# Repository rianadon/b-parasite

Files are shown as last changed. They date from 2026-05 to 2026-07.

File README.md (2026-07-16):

# b-parasite
<p align="center">
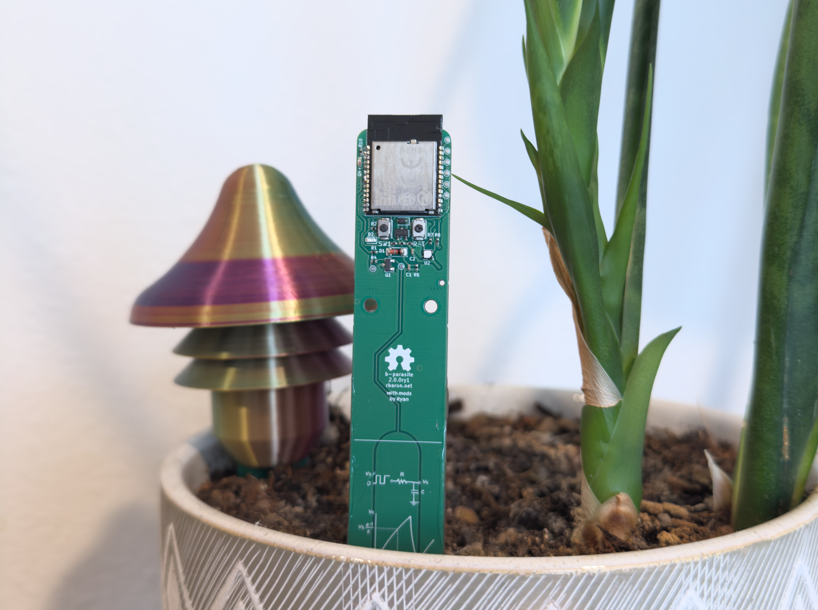
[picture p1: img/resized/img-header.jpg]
PCB in the soil
  <br>
  <i>This image is just for showing off the full PCB.<br>The sensor must be pushed down to the horizontal white line to work properly.</i>
</p>

<a href='https://cosmos-store.ryanis.cool/products/b-parasite-soil-moisture-sensor' target="_blank">Buy at Cosmos Store</a>

This is my fork of [b-parasite](https://github.com/rbaron/b-parasite), an open source soil moisture and ambient temperature/humidity/light sensor. Notable changes are:
- I changed the bluetooth module to MinewSemi nrf52840-MS88SF21 because I have extra from other projects.
- I've added a USB-C connector, and the bluetooth module is programmed with the [Adafruit nRF52 bootloader](https://github.com/rianadon/Adafruit_nRF52_Bootloader). The module can now be powered by either the coin cell and/or USB. If both are plugged in, priority is given to USB. Do be careful to ground yourself before plugging in USB. There was not room for ESD diodes on the PCB.
- Instead of feeding the battery directly to the chip voltage, I utilize the internal LDO to step down the voltage. This has several benefits. Battery life is extended due to running the chip and wireless transmitter at lower voltage, wireless transmission is consistent regardless of battery voltage, and there is no need to calibrate across different voltages. Only 1 measurement each of wet/dry moisture and sun luminosity are required to calibrate the sensor.
- Utilizing a USB COM port, calibration can now easily be performed without any specialized hardware.
- I've changed a few components to what's in stock on LCSC. The most noticeable of these is I replaced the Sensirion SHTC3, which was not in stock at the time of ordering, with a cheap clone. It's accurate within a few degrees F.

<p align="center">
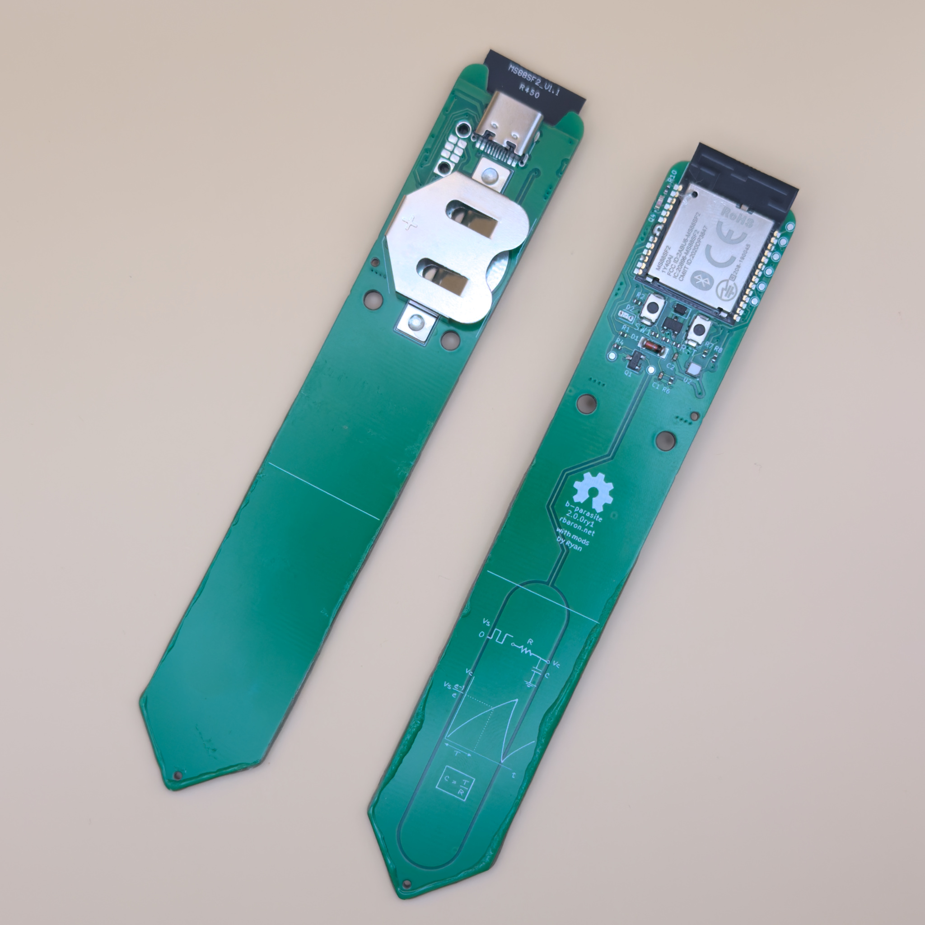
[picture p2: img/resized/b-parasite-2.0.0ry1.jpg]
PCB front and back photo
  
</p>

Instead of version tags I publish the software binaries on every commit. Check the [releases](https://github.com/rianadon/b-parasite/releases) to grab your preferred UF2. There are binaries for both BLE and Zigbee. I've tested both; while BLE is supposedly the more stable one I've been using Zigbee without issues.

To upload code, plug the b-parasite into your computer with a usb-c cable and press the reset button (RST) two times in quick succession. It's circled in red below. The LED (D2) will start pulsing in and out, and you'll see a removable drive named `BPARASITE` appear. Drag your `.uf2` file over to this drive (or copy and paste it in). Once it's copied, the microcontroller will automatically reboot with the new firmware. For building the firmware yourself or performing your own calibration, see [code/README.md](code/README.md).

<p align="center">
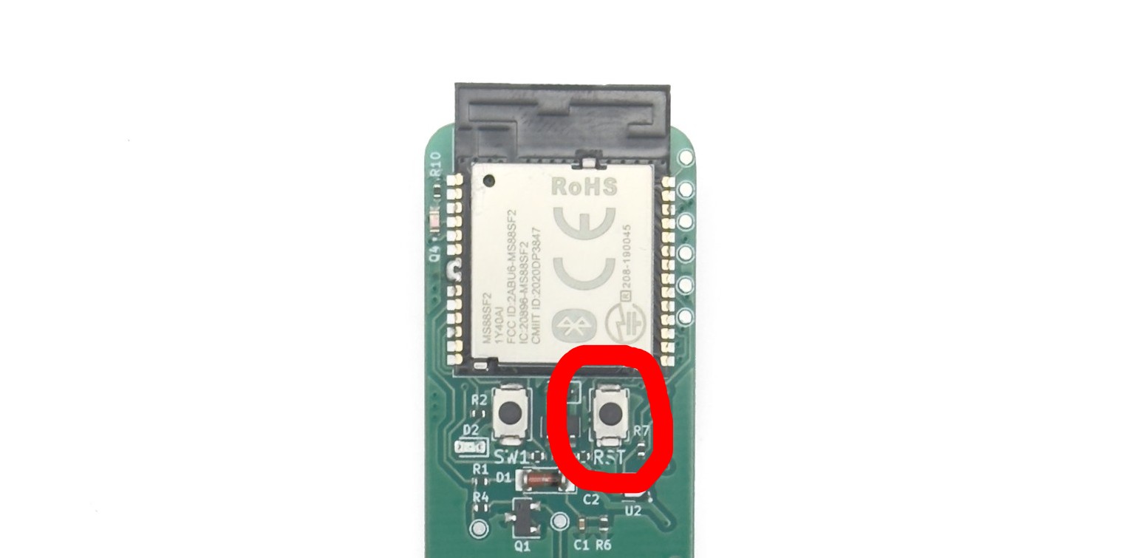
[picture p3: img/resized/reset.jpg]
location of reset button on the PCB
    
</p>

**Errata:** On the PCB I accidentally routed the sensor to P0.26, which does not support analog input. Therefore I've solder bridged P0.26 to P0.04 and used P0.04 as the sensor pin in the code. If you are manufacturing the PCBs in my fork yourself, I suggest you edit the PCB to connect SENS_OUT to P0.04 so that the solder bridge is not required.

Speaking of building these yourself, the most economical option is to order the PCBs with only the top soldered then solder on the USB connector and coin cell holder yourself with a stencil.

The original README is below:

---------------

b-parasite is an open source soil moisture and ambient temperature/humidity/light sensor.

# Features
* Capacitive Soil moisture sensor - see [this blog post](https://rbaron.net/blog/2021/04/05/How-capacitive-soil-moisture-sensors-work.html), [this Twitter thread](https://twitter.com/rbaron_/status/1367182806368071685), and [this post](https://wemakethings.net/2012/09/26/capacitance_measurement/) for nice resources on how they work
* Air temperature and humidity sensor using a [Sensirion's SHTC3](https://www.sensirion.com/en/environmental-sensors/humidity-sensors/digital-humidity-sensor-shtc3-our-new-standard-for-consumer-electronics/)
* Light sensor using an [ALS-PT19](https://en.everlight.com/wp-content/plugins/ItemRelationship/product_files/pdf/ALS-PT19-315C-L177-TR8_V8.pdf) phototransistor
* Powered by a common CR2032 coin cell, potentially for over two years
* Support for [nRF52840](https://www.nordicsemi.com/products/nrf52840) and [nRF52833](https://www.nordicsemi.com/products/nrf52833) modules
* Open hardware and open source design

# Software
This repository also hosts a few different firmware samples for b-parasite.

|Sample|Description|Extra Documentation|
|---|---|---|
|[samples/ble](./code/samples/ble)|This is the most battle-tested and useful firmware. It periodically reads all sensors and broadcast them via Bluetooth Low Energy (BLE). It works with [Home Assistant](https://www.home-assistant.io/) + [BTHome](https://bthome.io/) out of the box. |[Docs](./code/samples/ble/README.md)|
|[samples/zigbee](./code/samples/zigbee)| An experimental/educational/exploratory basic Zigbee sample built on [nRF Connect + ZBOSS](https://developer.nordicsemi.com/nRF_Connect_SDK/doc/latest/nrf/ug_zigbee.html). It integrates with [Home Assistant](https://www.home-assistant.io/) via [ZHA](https://www.home-assistant.io/integrations/zha) or [Zigbee2MQTT](https://www.zigbee2mqtt.io/). |[Docs](./code/samples/zigbee/README.md)|
|[samples/blinky](./code/samples/blinky)| The classic "Hello, world" |-|
|[samples/soil-read-loop](./code/samples/soil-read-loop)| Reads the soil moisture sensor on a loop. Useful for experimenting and calibrating the sensor. |-|
|[samples/input](./code/samples/input)| Handles button presses. Useful for power profiling GPIO interrupts and testing debouncing for push switches on [boards that have them](https://github.com/rbaron/b-parasite/wiki/Hardware-Versions). |-|

# Documentation
Information about how to order, assemble, build the samples, protect the sensor and flash the firmware is on [the Wiki](https://github.com/rbaron/b-parasite/wiki).

# Repository Organization
* [code/](./code/) - A [`west workspace`](https://docs.zephyrproject.org/latest/develop/west/workspaces.html) containing the common `prstlib` module library and samples, built with Nordic's [nRF Connect SDK](https://www.nordicsemi.com/Products/Development-software/nrf-connect-sdk).
* [kicad/](./kicad/) - KiCad schematic, layout and fabrication files for the printed circuit board (PCB)
* [data/](data/) - data for testing and sensor calibration
* [bridge/](bridge/) - an [ESPHome](https://github.com/esphome/esphome)-based BLE-MQTT bridge
* [case/](case/) - a 3D printable case

<p align="center">
  b-parasite stuck into a small plant vase
</p>

# Case
<p align="center">
  Render of the original 3D printable case
</p>

We have three different 3D-printable cases:
1. Original snap-on case - [case/Top.stl](./case/Top.stl), [case/Bottom.stl](./case/Bottom.stl)
2. High airflow - [case/b_parasite_case_high_airflow.stl](./case/b_parasite_case_high_airflow.stl)
3. Mushroom-style - available on [Printables](https://www.printables.com/model/456571-mushroomcap-for-b-parasite-soil-moisture-sensor)
4. b-parasite Hat - available on [Printables](https://www.printables.com/model/901220-waterproof-case-for-b-parasite-soil-moisture-air-s)

# Accessories

Designs and hardware to help you, when building your own:
1. Desk holder for b-parasites [Printables](https://www.printables.com/de/model/566974-b-parasite-holder)

# License
The hardware and associated design files are released under the [Creative Commons CC BY-SA 4.0 license](https://creativecommons.org/licenses/by-sa/4.0/).
The code is released under the [MIT license](https://opensource.org/licenses/MIT).

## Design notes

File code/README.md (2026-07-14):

# b-parasite Firmware

This documentation is common to all firmwares inside the `code/` directory and covers general things like building, configuring common options, and flashing. Each firmware also has its own documentation which you should also read:

- [`samples/ble/README.md`](./samples/ble/README.md) — BLE advertising (BTHome / legacy b-parasite encoding)
- [`samples/zigbee/README.md`](./samples/zigbee/README.md) — Zigbee end device (ZHA / Zigbee2MQTT)

The instructions here are written to only apply to my `2.0.0ry1` revision (both hardware and software). For the older revision, you should refer to the original b-parasite documentation.

## Building

Use either [`scripts/build.sh`](./scripts/build.sh) or [`scripts/build-with-docker.sh`](./scripts/build-with-docker.sh) to build the firmware. I recommend using Docker (or Podman) if you have it installed.

```bash
# For BLE. Generates samples/ble/build_nrf52840_2.0.0ry1_dev/ble/zephyr/zephyr.uf2
scripts/build.sh ble nrf52840 2.0.0ry1 --uf2 -DCONFIG_BPARASITE_REGOUT0_2V1=y

# For Zigbee. Generates code/samples/zigbee/build_nrf52840_2.0.0ry1/zigbee/zephyr/zephyr.uf2
scripts/build.sh zigbee nrf52840 2.0.0ry1 --uf2  -DCONFIG_BPARASITE_REGOUT0_2V1=y
```

### Development Builds

Passing `--dev` applies the following modifications to the firmware:

- **Logs Sensor Readings Over USB Serial Port.**. Configures Zephyr to log to a USB CDC ACM virtual UART
- **Increases Log Verbosity**. `CONFIG_LOG_DEFAULT_LEVEL=4` + `CONFIG_PRSTLIB_LOG_LEVEL_DBG=y`
- **Samples much faster**. A shortened wake cadence (each sample picks its own — see `CONFIG_PRSTLIB_DEV_FAST_LOOP`)

The serial port will appear as COM* on Windows, `/dev/ttyACM*` on Linux, and `/dev/cu.usbmodem*` on MacOS. I've switched from screen to picocom to now [tio](https://github.com/tio/tio), which I wholeheartedly recommend, for connecting to serial device over the terminal.

```bash
# For a BLE development build. Generates
# samples/ble/build_nrf52840_2.0.0ry1_dev/zephyr/zephyr.uf2
scripts/build.sh ble nrf52840 2.0.0ry1 --uf2 --dev  -DCONFIG_BPARASITE_REGOUT0_2V1=y
```

Enabling USB hardware and sampling at the fast rate will quickly drain your battery. The dev builds are meant to be used when you have the b-parasite connected to USB.

## Selecting The Regulated Voltage

One of the changes I've made on the PCB is to wire `VDD` independently of `VDDH`, so you can utilize the internal LDO on the nRF52840 to step down the voltage. The lower the voltage, the longer your battery life but the weaker your wireless antenna. To change the voltage, add `-DCONFIG_BPARASITE_REGOUT0_*V*=y`) to the end of your `build.sh` command. The default is `REGOUT0_2V1`.

The choice also drives `CONFIG_BT_CTLR_TX_PWR_*`, which configures how powerful your radio will be. If you want finer control, you can override it with `-DCONFIG_PRSTLIB_RADIO_TX_PWR_DBM=0`/`4`/`8`.

| Kconfig | Chip VDD | BLE TX cap | Best for | Readings accurate down to | CR2032 life (ai estimate) |
|---|---|---|---|---|---|
| `REGOUT0_1V8` | 1.8 V | 0 dBm | Best battery life, but voltage is too low for LED to turn on | 1.3% battery | ~3.5 yr |
| `REGOUT0_2V1` | 2.1 V | 0 dBm | Recommended default for indoors. In cold temperatures, the voltage may be too low for the LED. | 5.4% battery | ~2.5–3.7 yr |
| `REGOUT0_2V4` | 2.4 V | +4 dBm | Recommended for outdoors due to more wireless range and greater LED voltage. | 16.4% battery | ~2.0–3.0 yr |

There's also `REGOUT0_2V7` (+4dBm), `REGOUT0_3V0` (+8dBm) and `REGOUT0_3V3` (+8dBm).  However, for all of these the sensor readings will scale linearly with voltage as the battery drops, instead of remaining stable. This is because the onboard LDO requires VDDH > VDD+0.3V to be stable, and CR2032 starts at 3.0V.

The voltage setting is stored in UICR flash. When the chip is booted with the firmware for the first time, it will write UICR and reboot if the voltage setting changed.

## Calibrating the Sensors

Because the LDO ensures a stable supply voltage, only one measurement is needed for calibrating the soil and light sensors.

Procedure:

1. Load a firmware with development mode (`--dev`) turned on (see *Development Builds* above) **with the same voltage configured that you will use in your firmware** . Open the serial port.
2. With the sensor sitting in **outside soil** and touching nothing, wait for log lines like:
    ```
    Read soil moisture 2: -3.24 | Raw 508 | V_drive: 2.10 | Dry: 510 | Wet: 179
    ```
   Record the **Raw** value (here, `508`) — this is your `PRSTLIB_SOIL_DRY_RAW`. Ignore "Dry"/"Wet"—they are the calibration the firmware is currently using.
3. With the sensor sitting outside or near sunlight, record the phototransistor value as well as the lux from your smartphone (there are quite a few lux meters). Look for the line that reads
    ```
    Photo: 687 lx (116 mV)
    ```
    Disregard the lux reading here, since that uses the firmware's preexisting calibration. Instead calculate `PRSTLIB_PHOTO_CURRENT_SUN_UA` = 21277 × reported current (mV) ÷ phone's illuminance reading (lux).
3. Submerge the sensor pads in tap water up to the printed line on the circuit board. Use the same Raw reading in step 2, which is now your `PRSTLIB_SOIL_WET_RAW`.
4. Build the UF2

```
./scripts/build.sh ble nrf52840 2.0.0ry1 --uf2 \
  -DCONFIG_BPARASITE_REGOUT0_2V1=y \
  -DCONFIG_PRSTLIB_SOIL_DRY_RAW=510 \
  -DCONFIG_PRSTLIB_SOIL_WET_RAW=170 \
  -DCONFIG_PRSTLIB_PHOTO_CURRENT_SUN_UA=3546
```

For the Zigbee firmware, replace `ble` with `zigbee`.

## Bootloader

I flash the Adafruit UF2 bootloader to the board. The b-parasite specific configuration is located in [my Adafruit_nRF52_Bootloader fork](https://github.com/rianadon/Adafruit_nRF52_Bootloader).

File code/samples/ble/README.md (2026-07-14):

# Bluetooth Low Energy (BLE)
In this sample, b-parasite sensors are periodically read and broadcast using Bluetooth Low Energy (BLE) dvertising packets.

## Configuration
Available configurations and their default values are in [`Kconfig`](./Kconfig). They are set in [`prj.conf`](./prj.conf). Here are some notable examples.

### Sleep Interval
To save energy, the board spends most of the time in a "deep sleep" state, in which most peripherals and radio are completely turned off. The period of sleep is controlled by the `PRST_SLEEP_DURATION_SEC` config.

### Advertising Duration
When it wakes up, the sample reads all sensors and keep broadcasting advertising packets for `PRST_BLE_ADV_DURATION_MSEC` before going back to sleep.

### Advertising Packet Encoding
There are different ways to encode the sensor data in a BLE advertising packet.

#### BTHome Encoding
[BTHome](https://bthome.io) is a new (as of Dec/2022) open standard for encoding sensor data in BLE applications. [Home Assistant](https://www.home-assistant.io/integrations/bthome/) supports it out of the box. This makes the deployment extra convenient, since no additional configuration is needed - Home Assistant will automatically detect b-parasites in range.

What's even more interesting is that by employing [ESPHome](https://esphome.io/) bridges with the [`bluetooth_proxy`](https://esphome.io/components/bluetooth_proxy.html) component, the range of BLE coverage can be transparently increased. Multiple ESPHome bridges will forward received BLE broadcasts to Home Assistant.

This is what a typical deployment with BTHome looks like:
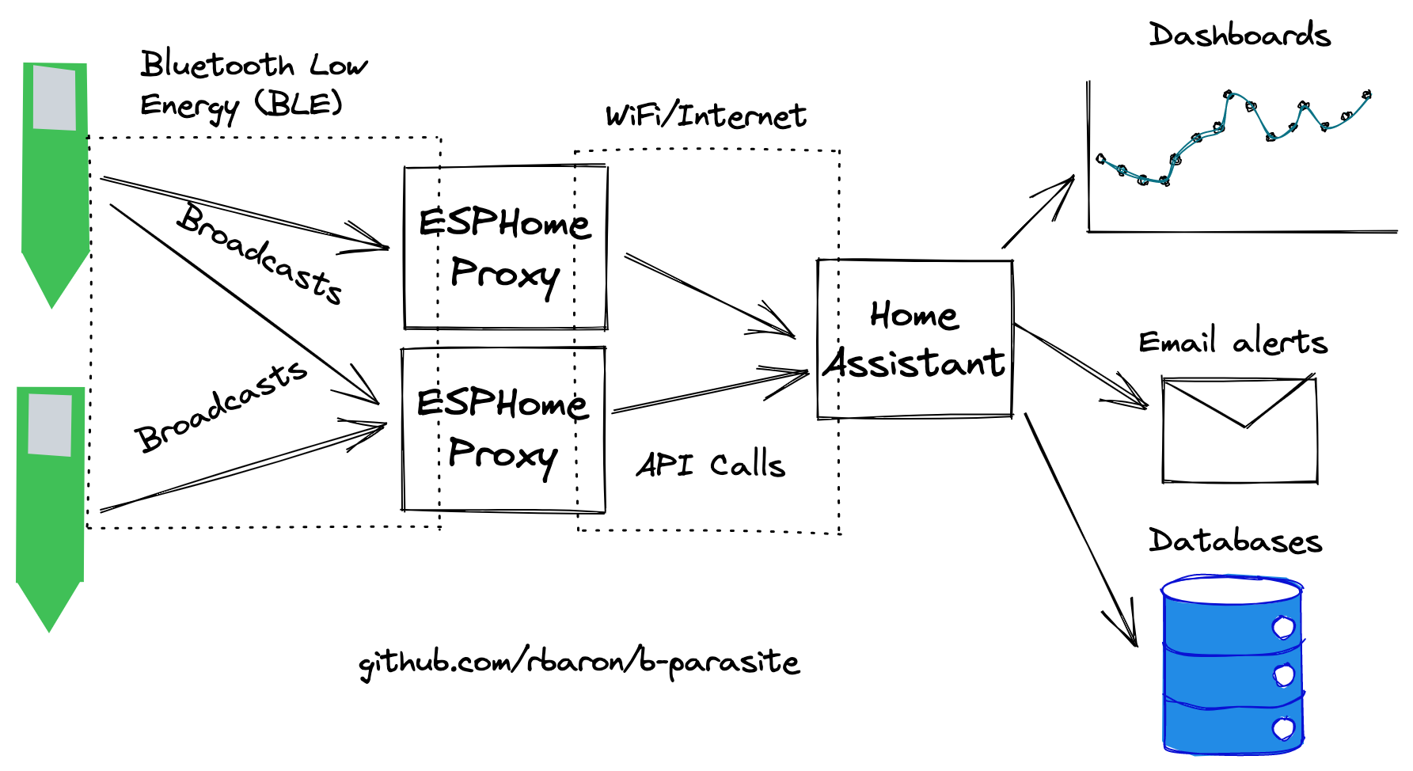
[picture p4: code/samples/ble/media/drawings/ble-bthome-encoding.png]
Topology with BTHome + Home Assistant


There are two versions of BTHome encodings supported by this sample:
* `PRST_BLE_ENCODING_BTHOME_V2=y` (**default**) uses the [BTHome V2](https://bthome.io/format/), supported by Home Assistant since version `2022.12`
* `PRST_BLE_ENCODING_BTHOME_V1=y` uses the [legacy BTHome V1](https://bthome.io/v1/), which was briefly in use
#### b-parasite Encoding
`PRST_BLE_ENCODING_BPARASITE_V2=y` selects the legacy encoding, used historically in this project. This is the encoding that the [`b_parasite`](https://esphome.io/components/sensor/b_parasite.html) ESPHome component understands.

With this encoding and a ESPHome + `b_parasite` component, this is an usual deployment topology:

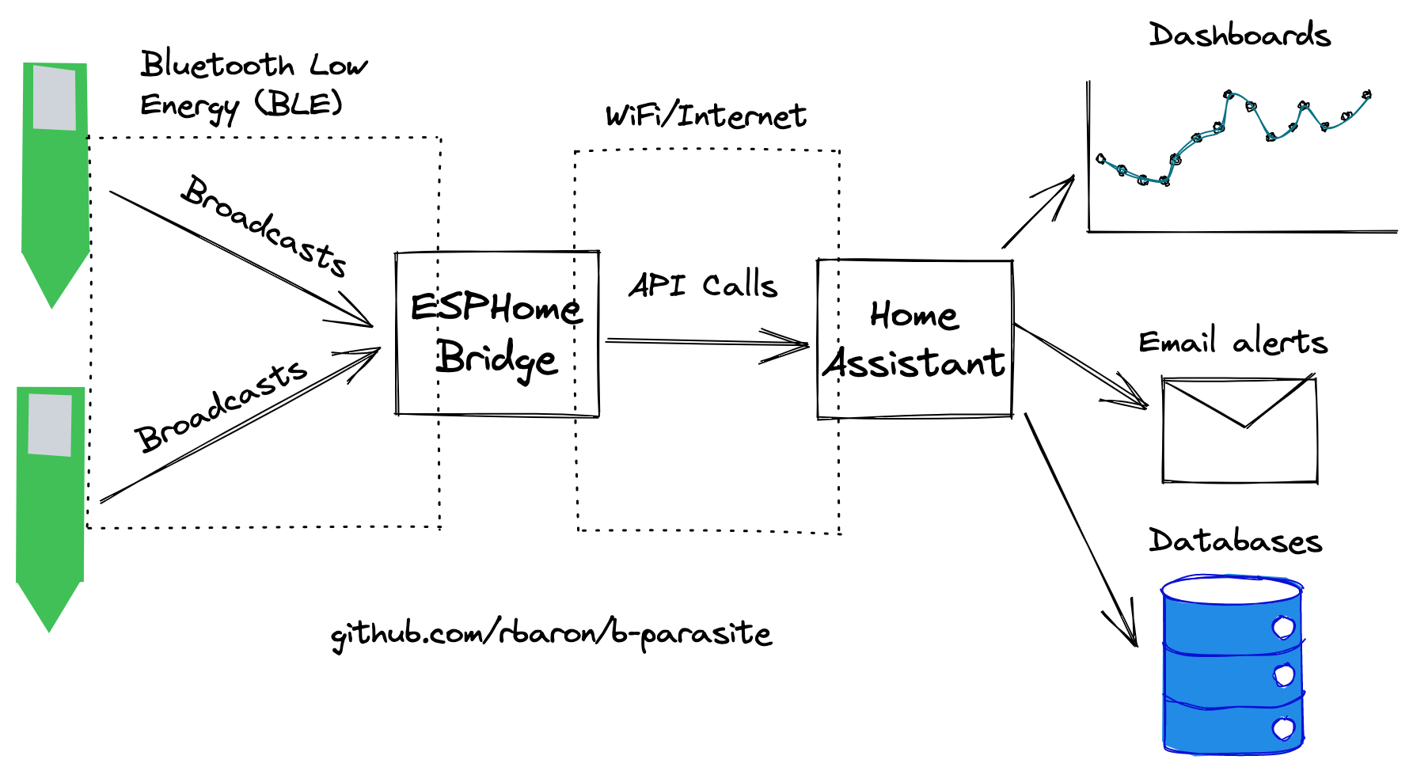
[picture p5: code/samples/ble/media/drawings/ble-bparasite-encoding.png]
Topology with Legacy encoding + Home Assistant


The disadvantages of this encoding are:
- Each b-parasite has to be configured in the ESPHome component
- Range is limited, unless multiple ESPHome bridges are deployed with the same static configuration

## Building

See [`code/README.md`](../../README.md) for the build script, the container wrapper, the `REGOUT0` voltage table, and the soil-moisture calibration procedure — all shared with the zigbee sample. What follows is ble-specific.

### Production build (deploy to battery)

Default `prj.conf` settings: 10-min wake cadence, 1-s advertise window, no USB stack, no logging. Pair with the `2.0.0ry1` board revision (CR2032 wired to VDDH) and pick a `REGOUT0` voltage that matches your hardware (see [`prstlib/boards/bparasite/Kconfig.regout0`](../../prstlib/boards/bparasite/Kconfig.regout0)).

```
./scripts/build-with-docker.sh ble nrf52840 2.0.0ry1 --uf2 \
  -DCONFIG_BPARASITE_REGOUT0_2V1=y
```

Output: `samples/ble/build_nrf52840_2.0.0ry1/ble/zephyr/zephyr.uf2` (~400 KB).

BLE picks its `CONFIG_BT_CTLR_TX_PWR_*` choice from `PRSTLIB_RADIO_TX_PWR_DBM`, which the `REGOUT0` choice sets (0 dBm at 1.8–2.1 V, 4 at 2.4–2.7 V, 8 at 3.0–3.3 V).

### Development build (bring-up, sensor calibration, debugging)

Same command + `--dev` (see [`code/README.md`](../../README.md#development-builds) for what the snippet turns on). For ble it also sets `CONFIG_PRST_SLEEP_DURATION_MSEC=5000`, advertising every ~6 s instead of every 10 min.

```
./scripts/build-with-docker.sh ble nrf52840 2.0.0ry1 --uf2 --dev \
  -DCONFIG_BPARASITE_REGOUT0_2V1=y
```

Output: `samples/ble/build_nrf52840_2.0.0ry1_dev/ble/zephyr/zephyr.uf2` (~445 KB).

## Battery Life
**tl;dr**: Theoretically well over two years with default settings.

While in deep sleep, the board consumes around `3.0 uA`:

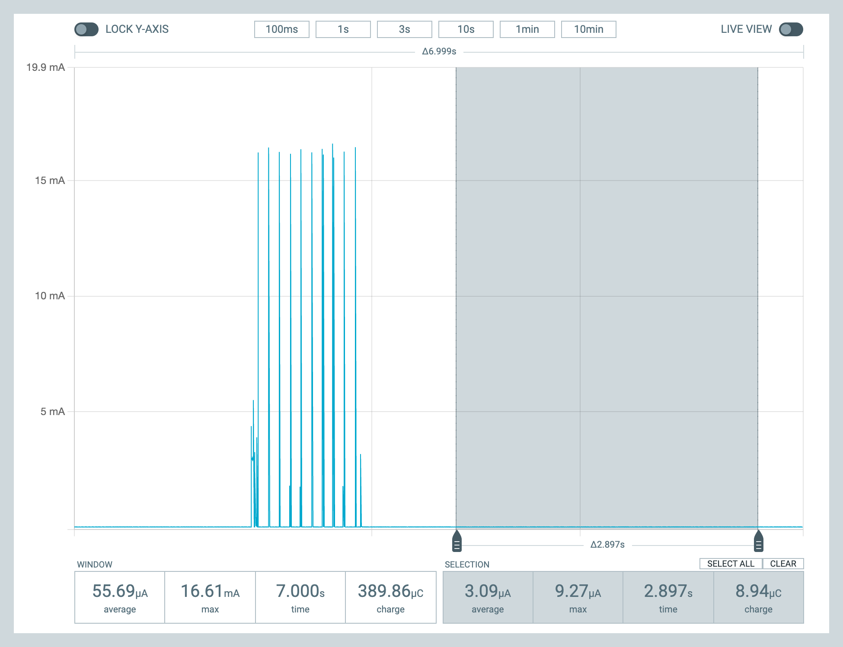
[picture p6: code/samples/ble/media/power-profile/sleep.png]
Sleep current consumption


In the active broadcasting state, the average power consumption is highly dependant on the advertising interval.

With the default settings (in the `[30, 40] ms` range), we see an average of around `810 uA`:

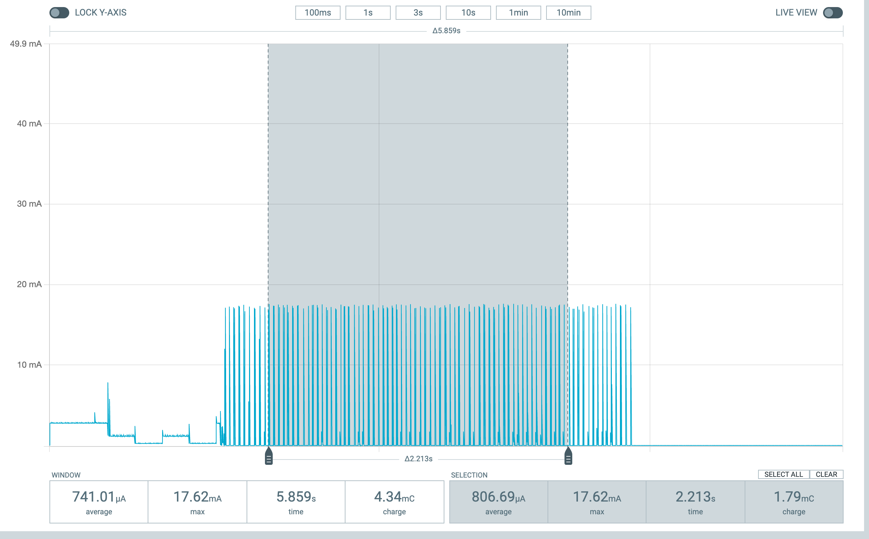
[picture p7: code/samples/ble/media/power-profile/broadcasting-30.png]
Broadcasting with 30 ms current consumption


If for example we lower the connection interval to the SDK defaults (`[100, 150] ms`, roughly trading off range for power), the average current consumption is around `345 uA`:

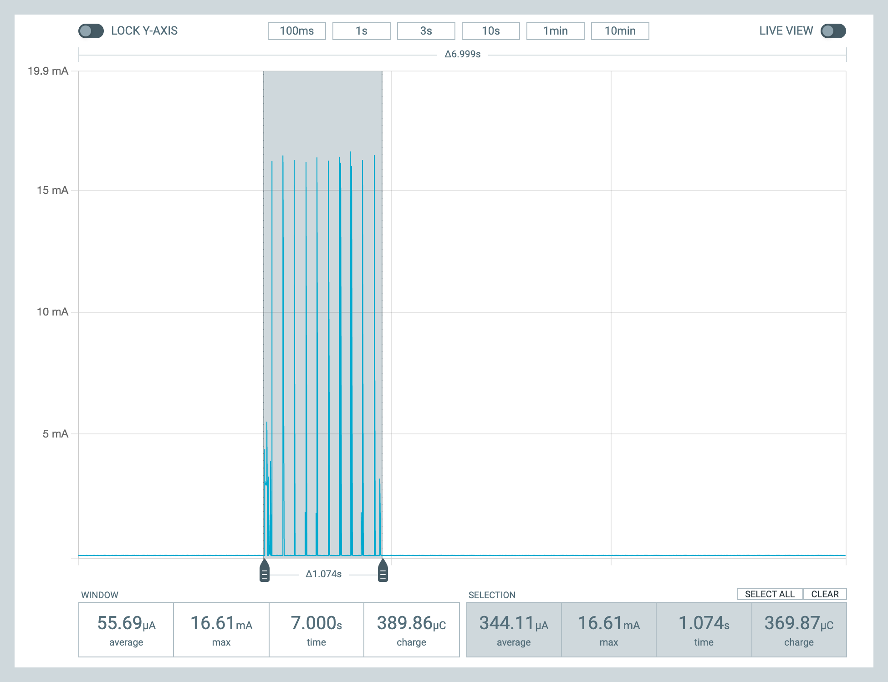
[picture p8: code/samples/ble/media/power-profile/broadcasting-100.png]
Broadcasting with 100ms current consumption


With a `200 mAh` CR2032 battery, we can use [this spreadsheet](https://docs.google.com/spreadsheets/d/157JQiX20bGkTrlbvWbWRrs_WViL3MgVZffSCWRR7uAI/edit#gid=0) to estimate the battery life to over two years. Note that this is a simplified model and results in practice may vary.

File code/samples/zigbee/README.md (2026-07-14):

# Zigbee firmware sample
This sample is adapted from the [zigbee_template](https://developer.nordicsemi.com/nRF_Connect_SDK/doc/latest/nrf/samples/zigbee/template/README.html) from the nRF Connect SDK. It's a basic experimental/educational/exploratory firmware sample for b-parasite.

## Clusters
These [clusters](https://en.wikipedia.org/wiki/Zigbee#Cluster_library) are defined in the sample:

|Cluster ID|Name|
|---|---|
|0x0001|Power Configuration|
|0x0400|Illuminance Measurement|
|0x0402|Temperature Measurement|
|0x0405|Relative Humidity Measurement|
|0x0408|Soil Moisture Measurement|

## Pairing Mode
The sample will first boot and start looking for a Zigbee coordinator - in pairing mode. The onboard LED will be flashing once a second while in this mode. Once a suitable network is found, the LED will briefly flash 3 times and remain off.

### Factory Reset
A factory reset will make b-parasite forget its network pairing information and switch to pairing mode. There are two (mutually exclusive) methods to perform a factory reset, controlled by the `CONFIG_PRST_ZB_FACTORY_RESET_METHOD` config flag.

#### Factory Reset Method 1 (default) - Double reset
Resetting b-parasite twice in the timestamp of 5 seconds will perform a factory reset. With this method, both shorting the `RST` pin to ground and removing-inserting the battery counts as a reset.

For better results, wait > 1 and < 5 seconds second between the resets. The LED will flash a total of 8 times to indicate it worked.

#### Factory Reset Method 2 - Reset Pin
In this method, there's a distinction between two reset modes.

#### Power up mode
The device enters this mode when it is powered. For example, swapping an old battery or connecting to eternal power. This is the "usual" reset mode, and joined networks will be remembered.

#### Reset pin mode
If the device's RESET pin is briefly grounded, the device will effectively be **factory reset**. The device will leave its previous network and start looking for a new one.

While it works, this method can be finicky - an accidental pin reset will perform an unwanted factory reset.

## Configs
Available options in `Kconfig`. Notable options:
* `CONFIG_PRST_ZB_SLEEP_DURATION_SEC`: amount of time (in seconds) the device sleeps between reading all sensors and updating its clusters
* `CONFIG_PRST_ZB_PARENT_POLL_INTERVAL_SEC`: amount of time (in seconds) the device waits between polling its parent for data

## Home Assistant Integration
This firmware sample has only been tested with Home Assistant, using one of the following integrations.

### Zigbee Home Automation (ZHA)
With the [ZHA](https://www.home-assistant.io/integrations/zha) Home Assistant integration, b-parasite should work out of the box.

### Zigbee2MQTT & Home Assistant
With [Zigbee2MQTT](https://zigbee2mqtt.io/), a custom converter is required. The [b-parasite.js](b-parasite.js) file contains such a converter. See [Support new devices](https://www.zigbee2mqtt.io/advanced/support-new-devices/01_support_new_devices.html) for instructions.

## Building

See [`code/README.md`](../../README.md) for the build script, the container wrapper, the `REGOUT0` voltage table, and the soil-moisture calibration procedure — all shared with the ble sample. What follows is zigbee-specific.

### Radio TX power

**Note on Zigbee radio TX power:** ZBOSS in NCS routes TX power through its own path (`zb_trans_set_tx_power()`) rather than `CONFIG_NET_L2_IEEE802154_RADIO_DFLT_TX_POWER`, so the board defconfig's `BT_CTLR_TX_PWR_*` choice doesn't reach it. Instead, `main.c` reads `CONFIG_PRSTLIB_RADIO_TX_PWR_DBM` (derived from `REGOUT0` in [`Kconfig.defconfig`](../../prstlib/boards/bparasite/Kconfig.defconfig)) and calls `zb_trans_set_tx_power()` right after `zigbee_enable()`. To override, set `CONFIG_PRSTLIB_RADIO_TX_PWR_DBM=<dBm>` in your build.

### Partition layout

NCS Zigbee NVRAM (`ncs-zigbee/subsys/osif/zb_nrf_nvram.c`) hard-includes `pm_config.h`, so unlike the other samples we can't disable Partition Manager. Instead, [`pm_static.yml`](./pm_static.yml) pins the partitions to match the Adafruit UF2 bootloader:

| Region | Range | Purpose |
|---|---|---|
| `softdevice_reserved` | 0x000000–0x026000 | MBR + SoftDevice slot (reserved, unused) |
| `app` | 0x026000–0x0EC000 | 792 KiB application image |
| `settings_storage` | 0x0EC000–0x0F4000 | 32 KiB LittleFS for ZBOSS network credentials |
| `uf2_bootloader_reserved` | 0x0F4000–0x100000 | Adafruit UF2 bootloader (don't touch) |

The build script (`scripts/build.sh`) keeps Partition Manager enabled whenever the sample ships a `pm_static.yml`. For samples without one (ble, blinky, input, soil-read-loop), `--uf2` flips PM off so the linker honours the DT `slot0_partition` offset instead.

### Production build (deploy to battery)

Default `prj.conf` settings: 60-s sleep cadence between sensor reads, 10-s parent poll interval, no console output (no USB, no UART, no RTT).

```
./scripts/build-with-docker.sh zigbee nrf52840 2.0.0ry1 --uf2 \
  -DCONFIG_BPARASITE_REGOUT0_2V1=y
```

Output: `samples/zigbee/build_nrf52840_2.0.0ry1/zigbee/zephyr/zephyr.uf2` (~825 KB).

### Development build (bring-up, logs over USB)

Same command + `--dev` (see [`code/README.md`](../../README.md#development-builds) for what the snippet turns on). For zigbee it also sets `CONFIG_PRST_ZB_SLEEP_DURATION_SEC=10`, reading sensors every 10 s instead of 60 s.

```
./scripts/build-with-docker.sh zigbee nrf52840 2.0.0ry1 --uf2 --dev \
  -DCONFIG_BPARASITE_REGOUT0_2V1=y
```

Output: `samples/zigbee/build_nrf52840_2.0.0ry1_dev/zigbee/zephyr/zephyr.uf2` (~903 KB).

After pairing a calibration build, sanity-check it in ZHA / Zigbee2MQTT: sensor in air reads ~0% moisture, submerged ~100%.

## Battery Life
While sleeping, the device consumes around 2 uA:
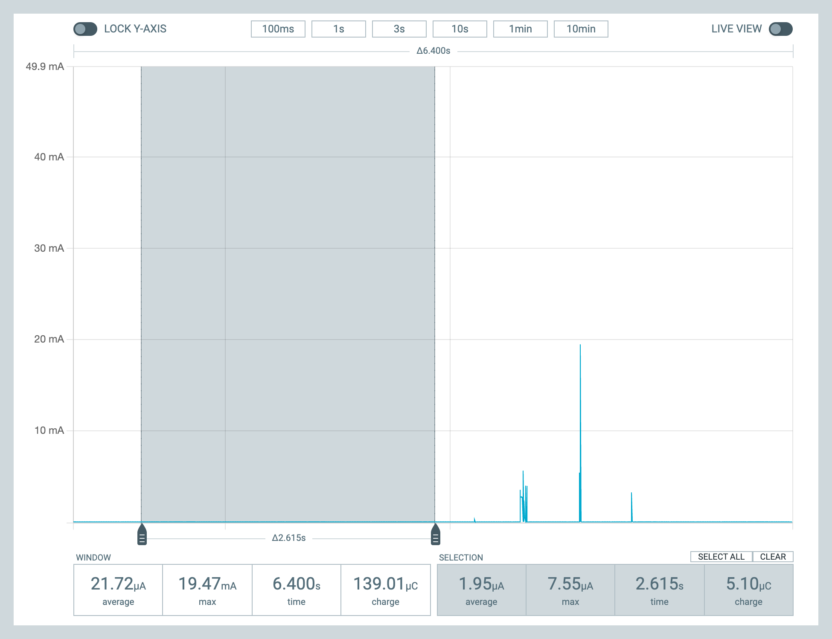
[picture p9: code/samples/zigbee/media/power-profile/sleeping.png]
sleeping current

In the active cycle, it averages around 125 uA for 1 second:
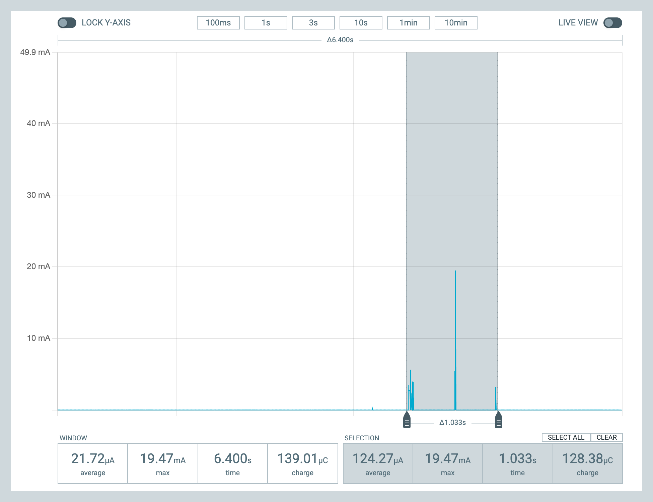
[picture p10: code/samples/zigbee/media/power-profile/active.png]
active current


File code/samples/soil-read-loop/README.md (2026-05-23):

# Calibration
A sample for calibrating b-parasites soil moisture analog-to-digital conversion.

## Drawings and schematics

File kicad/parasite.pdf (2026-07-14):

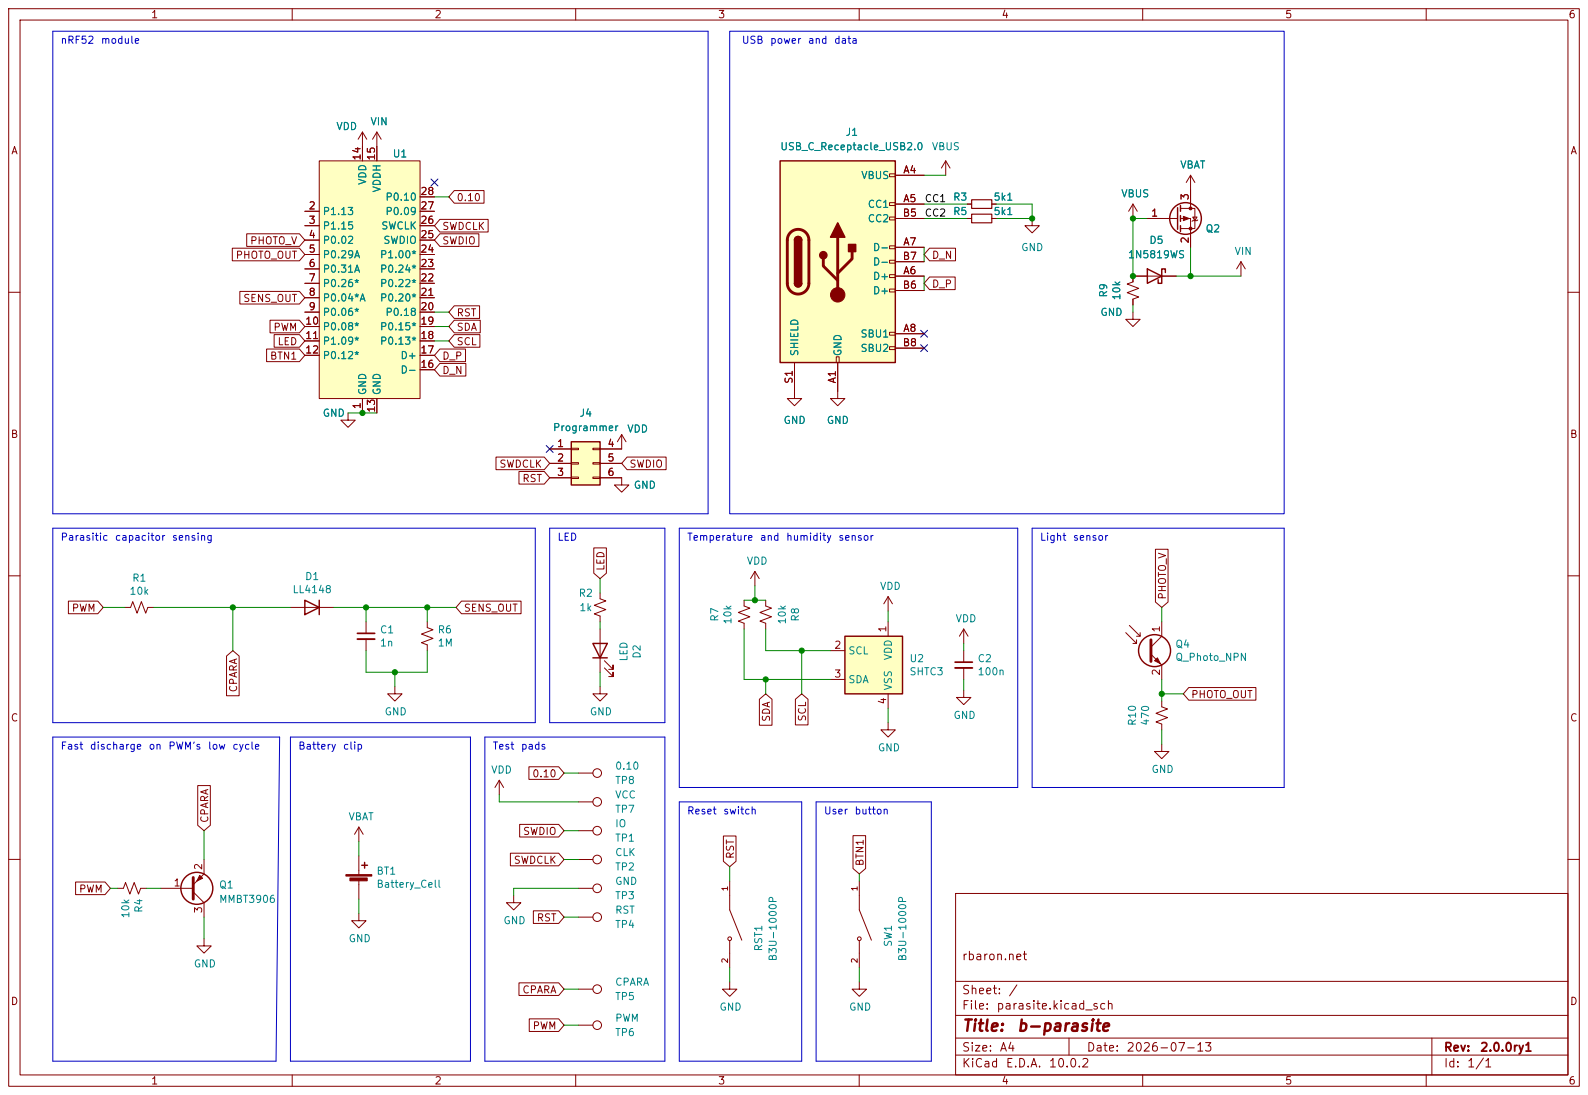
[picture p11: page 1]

USB power and data

1 P1.13 2 P1.15 3 P0.02 4 P0.29A 5 P0.31A 6 P0.26* 7 P0.04*A 8 P0.06* 9 P0.08* 10 P1.09* 11 P0.12* 12 GND 13 VDD 14 VDDH 15 D- 16 D+ 17 P0.13* 18 P0.15* 19 P0.18 20 P0.20* 21 P0.22* 22 P0.24* 23 P1.00* 24 SWDIO 25 SWCLK 26 P0.09 27 P0.10 28 GND

Test pads Parasitic capacitor sensing

Temperature and humidity sensor Reset switch

Light sensor User button

Fast discharge on PWM’s low cycle

Size: A4 | Rev: 2.0.0ry1
KiCad E.D.A. 10.0.2 | Id: 1/1

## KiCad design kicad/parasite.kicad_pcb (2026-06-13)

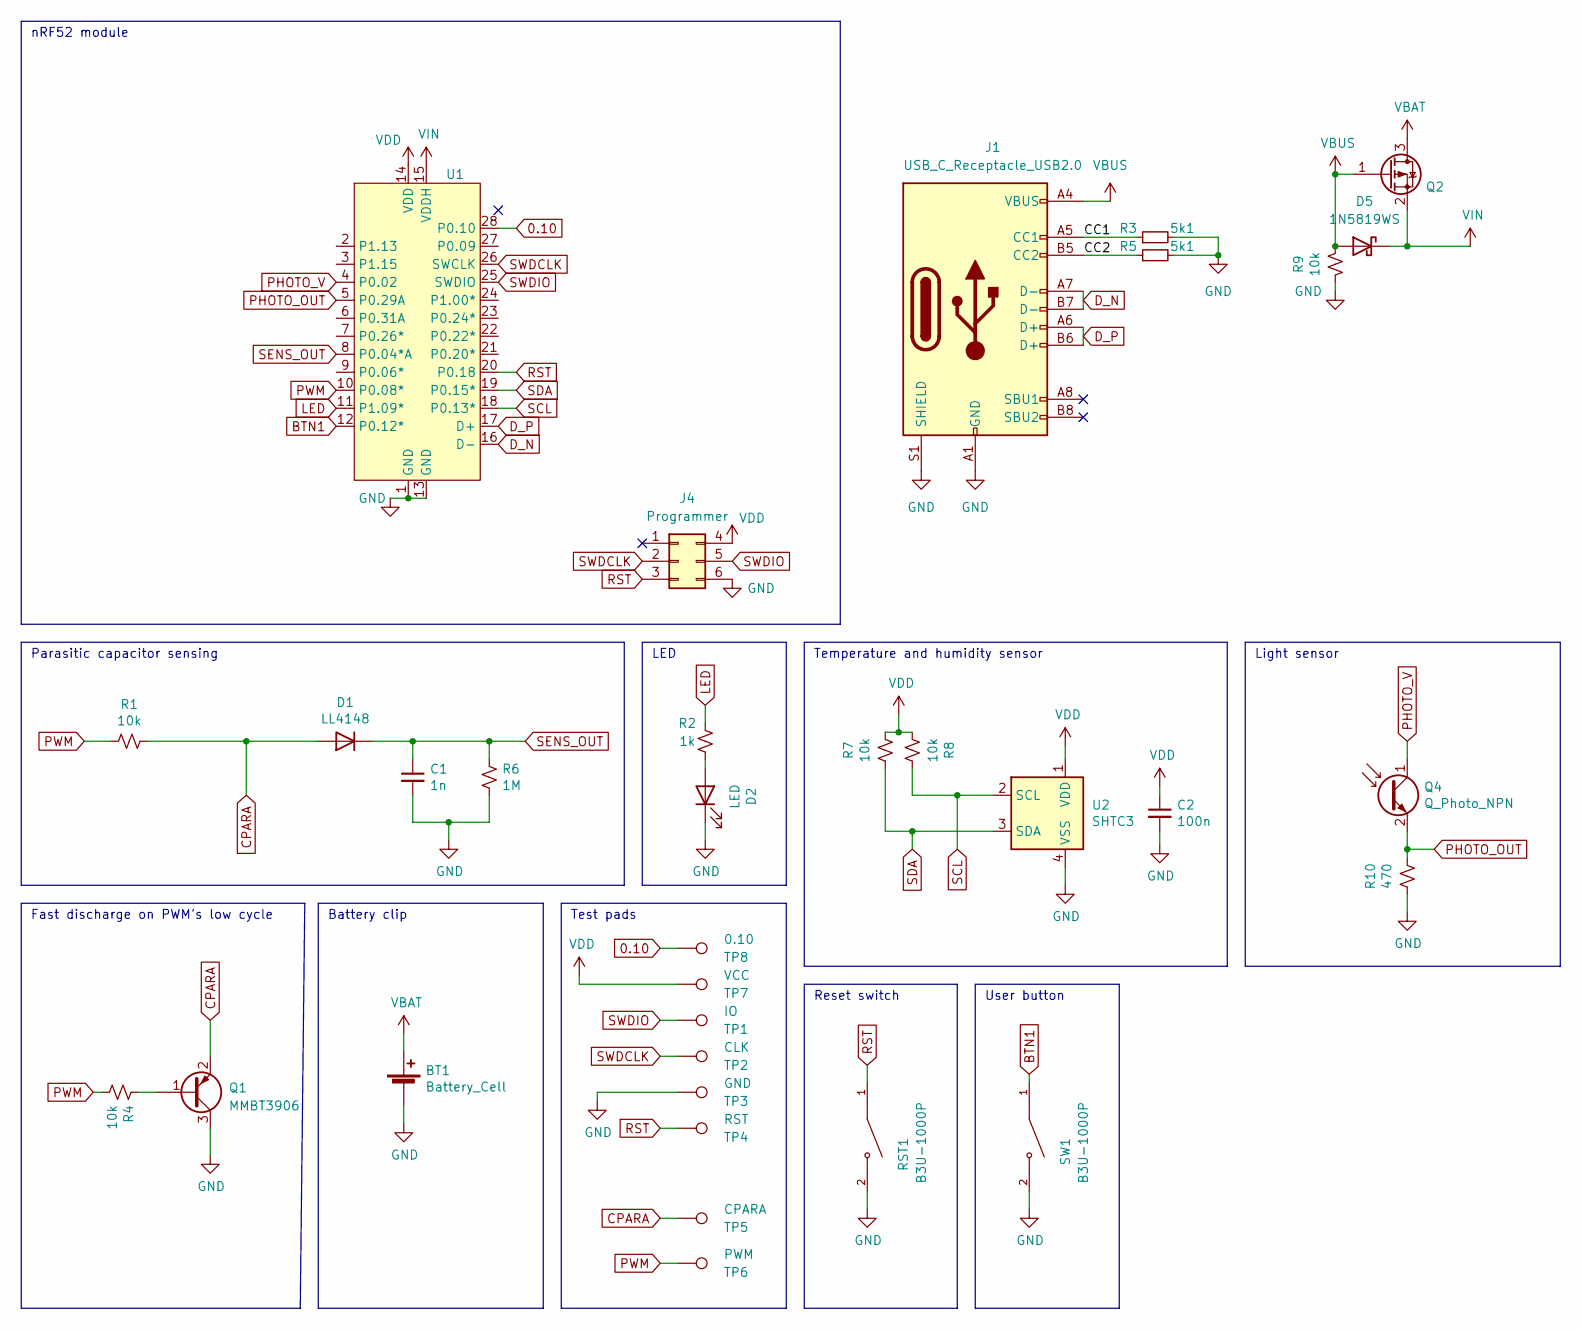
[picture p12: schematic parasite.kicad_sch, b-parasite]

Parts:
BT1: Battery_Cell; BatteryHolder_Keystone_3002_1x2032
C1: 1n; C_0402_1005Metric; LCSC C1523
C2: 100n; C_0402_1005Metric; LCSC C1525
D1: LL4148; D_MiniMELF; LCSC C3011166
D2: LED; LED_0603_1608Metric; LCSC C2286
D5: 1N5819WS; D_SOD-323
J1: USB_C_Receptacle_USB2.0; USB_C_Receptacle_HRO_TYPE-C-31-M-12; LCSC C165948
J4: Programmer; j2thing
Q1: MMBT3906; SOT-23; LCSC C2910191
Q2: Q_PMOS_SGD; SOT-23; LCSC C15127
Q4: Q_Photo_NPN; TR8; LCSC C146233
R1, R4, R7, R8, R9: 10k; R_0402_1005Metric; LCSC C25744
R2: 1k; R_0402_1005Metric; LCSC C11702
R3, R5: 5k1; R_0402_1005Metric; LCSC C25905
R6: 1M; R_0402_1005Metric; LCSC C26083
R10: 470; R_0402_1005Metric; LCSC C25117
RST1: B3U-1000P; SW_Push_SPST_NO_Xunpu; LCSC C720477
SW1: B3U-1000P; SW_Push_SPST_NO_Xunpu; LCSC C720477
TP1: IO; TestPoint_Pad_D1.0mm
TP2: CLK; TestPoint_Pad_D1.0mm
TP3: GND; TestPoint_Pad_D1.0mm
TP4: RST; TestPoint_Pad_D1.0mm
TP5: CPARA; TestPoint_Pad_D1.0mm
TP6: PWM; TestPoint_Pad_D1.0mm
TP7: VCC; TestPoint_Pad_D1.0mm
TP8: 0.10; TestPoint_Pad_D1.0mm
U1: XCVR_MS88SF2
U2: SHTC3; Sensirion_DFN-4-1EP_2x2mm_P1mm_EP0.7x1.6mm; LCSC C54946588

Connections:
0.10: TP8.1 (1_1), U1.28 (P0.10)
/CC1: J1.A5 (CC1), R3.1
/CC2: J1.B5 (CC2), R5.1
BTN1: SW1.1, U1.12 (P0.12*)
CPARA: D1.2 (A), Q1.2 (E), R1.2, TP5.1 (1_1)
D_N: J1.A7 (D-), J1.B7 (D-), U1.16 (D-)
D_P: J1.A6 (D+), J1.B6 (D+), U1.17 (D+)
GND: BT1.2 (-), C1.2, C2.2, D2.1 (K), J1.A1 (GND), J1.A12 (GND), J1.B1 (GND), J1.B12 (GND), J1.S1 (SHIELD), J4.6, Q1.3 (C), R3.2, R5.2, R6.2, R9.2, R10.1, RST1.2, SW1.2, TP3.1 (1_1), U1.1 (GND), U1.13 (GND), U2.4 (VSS)
LED: R2.2, U1.11 (P1.09*)
unnamed: D2.2 (A), R2.1
unnamed: Q1.1 (B), R4.1
PHOTO_OUT: Q4.2 (E), R10.2, U1.5 (P0.29A)
PHOTO_V: Q4.1 (C), U1.4 (P0.02)
PWM: R1.1, R4.2, TP6.1 (1_1), U1.10 (P0.08*)
RST: J4.3, RST1.1, TP4.1 (1_1), U1.20 (P0.18)
SCL: R8.2, U1.18 (P0.13*), U2.2 (SCL)
SDA: R7.1, U1.19 (P0.15*), U2.3 (SDA)
SENS_OUT: C1.1, D1.1 (K), R6.1, U1.7 (P0.26*), U1.8 (P0.04*A)
SWDCLK: J4.2, TP2.1 (1_1), U1.26 (SWCLK)
SWDIO: J4.5, TP1.1 (1_1), U1.25 (SWDIO)
VBAT: BT1.1 (+), Q2.3 (D)
VBUS: D5.2 (A), J1.A4 (VBUS), J1.A9 (VBUS), J1.B4 (VBUS), J1.B9 (VBUS), Q2.1 (G), R9.1
VDD: C2.1, J4.4, R7.2, R8.1, TP7.1 (1_1), U1.14 (VDD), U2.1 (VDD)
VIN: D5.1 (K), Q2.2 (S), U1.15 (VDDH)

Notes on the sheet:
Fast discharge on PWM’s low cycle
Temperature and humidity sensor
LED
nRF52 module
Parasitic capacitor sensing
Test pads
Light sensor
Reset switch
User button
Battery clip

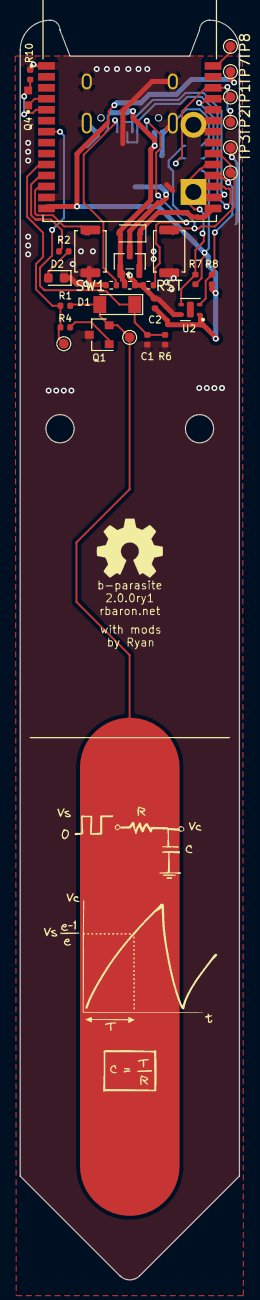
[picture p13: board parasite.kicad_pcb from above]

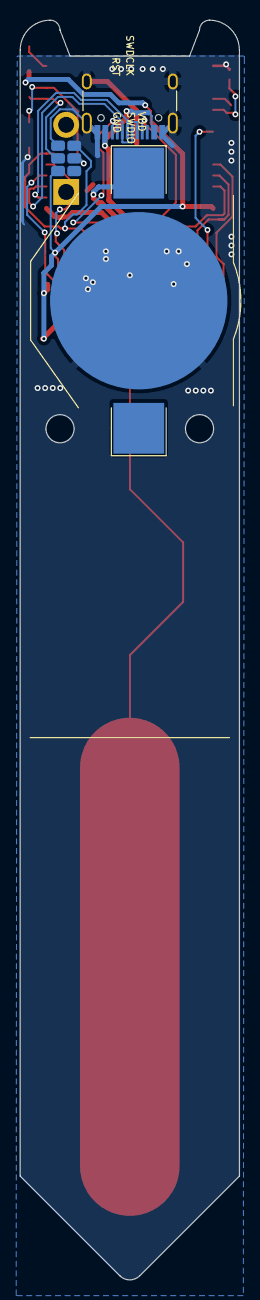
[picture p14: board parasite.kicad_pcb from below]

Board: 2 copper layers, 22.0 x 126.4 mm, 33 parts (3 on the bottom side), 24 nets.

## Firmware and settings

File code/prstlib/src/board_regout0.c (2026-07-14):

/*
 * Boot-time UICR.REGOUT0 programmer for bparasite/nRF52840.
 *
 * The chip's VDD output voltage in high-voltage mode (VDDH >= 2.5 V, e.g.
 * CR2032 wired to VDDH) is stored in UICR.REGOUT0. The user picks the
 * desired voltage at build time via CONFIG_BPARASITE_REGOUT0_*; this hook
 * writes UICR on first boot, then resets so the new voltage takes effect.
 *
 * Snapshots NRF_UICR_Type, erases UICR via the nrfx HAL, modifies REGOUT0
 * in the snapshot, writes the whole struct back. Bytes past the struct
 * (chip-reserved tail) are left at 0xFFFFFFFF after the erase — NCS and
 * the Nordic toolchain don't populate them, so nothing real is lost.
 *
 * Only runs when MAINREGSTATUS == HIGH. In normal-voltage mode the
 * regulator is bypassed and REGOUT0 has no effect.
 *
 * Registered as SYS_INIT(PRE_KERNEL_1) so it runs before any driver
 * that depends on a specific VDD. Requires prstlib to be built as a
 * zephyr_library so the init record survives the link.
 *
 * If the erase fails or the post-write readback of REGOUT0 doesn't match
 * the intended value, fatal_blink() drops the CPU into an infinite LED
 * blink so a half-programmed UICR can't be left to brick the board
 * silently — the user sees the failure and pulls the battery before
 * trusting the chip.
 */

#if defined(CONFIG_BOARD_BPARASITE_NRF52840)

#include <hal/nrf_gpio.h>
#include <hal/nrf_power.h>
#include <nrfx_nvmc.h>
#include <stdint.h>
#include <string.h>
#include <zephyr/devicetree.h>
#include <zephyr/init.h>
#include <zephyr/kernel.h>

/* led0 is a node label on every bparasite board revision (base DTS +
 * per-revision overlays). At PRE_KERNEL_1 the Zephyr GPIO driver isn't
 * up yet, so fatal_blink() pokes the nrf_gpio HAL directly using the
 * absolute pin number (port*32 + pin) derived from DT.
 */
#define LED_NODE DT_NODELABEL(led0)
#define LED_PORT DT_PROP(DT_GPIO_CTLR(LED_NODE, gpios), port)
#define LED_PIN DT_GPIO_PIN(LED_NODE, gpios)
#define LED_ABS_PIN NRF_GPIO_PIN_MAP(LED_PORT, LED_PIN)

static uint32_t desired_vout(void) {
#if CONFIG_BPARASITE_REGOUT0_1V8
  return UICR_REGOUT0_VOUT_1V8;
#elif CONFIG_BPARASITE_REGOUT0_2V1
  return UICR_REGOUT0_VOUT_2V1;
#elif CONFIG_BPARASITE_REGOUT0_2V4
  return UICR_REGOUT0_VOUT_2V4;
#elif CONFIG_BPARASITE_REGOUT0_2V7
  return UICR_REGOUT0_VOUT_2V7;
#elif CONFIG_BPARASITE_REGOUT0_3V0
  return UICR_REGOUT0_VOUT_3V0;
#elif CONFIG_BPARASITE_REGOUT0_3V3
  return UICR_REGOUT0_VOUT_3V3;
#else
#error "No BPARASITE_REGOUT0_* selected"
#endif
}

__attribute__((noreturn)) static void fatal_blink(void) {
  nrf_gpio_cfg_output(LED_ABS_PIN);
  for (;;) {
    nrf_gpio_pin_toggle(LED_ABS_PIN);
    k_busy_wait(100000);
  }
}

static int board_regulator_init(void) {
  if (nrf_power_mainregstatus_get(NRF_POWER) != NRF_POWER_MAINREGSTATUS_HIGH) {
    return 0;
  }

  const uint32_t want = desired_vout();
  const uint32_t cur =
      (NRF_UICR->REGOUT0 & UICR_REGOUT0_VOUT_Msk) >> UICR_REGOUT0_VOUT_Pos;

  if (cur == want) {
    return 0;
  }

  NRF_UICR_Type tmp;
  memcpy(&tmp, NRF_UICR, sizeof(tmp));
  tmp.REGOUT0 = (tmp.REGOUT0 & ~((uint32_t)UICR_REGOUT0_VOUT_Msk)) |
                (want << UICR_REGOUT0_VOUT_Pos);

  if (nrfx_nvmc_uicr_erase() != 0) {
    fatal_blink();
  }

  nrfx_nvmc_bytes_write(NRF_UICR_BASE, &tmp, sizeof(tmp));
  while (!nrfx_nvmc_write_done_check()) {
  }

  /* Readback verification: confirms the field we cared about landed.
   * If the chip is in a state that silently drops UICR writes (APPROTECT,
   * NVMC misconfig, hardware fault), this catches it before we reset
   * into an unknown VDD.
   */
  const uint32_t got =
      (NRF_UICR->REGOUT0 & UICR_REGOUT0_VOUT_Msk) >> UICR_REGOUT0_VOUT_Pos;
  if (got != want) {
    fatal_blink();
  }

  NVIC_SystemReset();
  return 0;
}

SYS_INIT(board_regulator_init, PRE_KERNEL_1, 0);

#endif /* CONFIG_BOARD_BPARASITE_NRF52840 */

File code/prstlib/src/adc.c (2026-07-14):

#include "prstlib/adc.h"

#include <math.h>
#include <zephyr/devicetree.h>
#include <zephyr/drivers/adc.h>
#include <zephyr/drivers/gpio.h>
#include <zephyr/drivers/pwm.h>
#include <zephyr/kernel.h>
#include <zephyr/logging/log.h>

#include "prstlib/macros.h"

LOG_MODULE_REGISTER(adc, CONFIG_PRSTLIB_LOG_LEVEL);

// PWM spec for square wave. Input to the soil sensing circuit.
static const struct pwm_dt_spec soil_pwm_dt =
    PWM_DT_SPEC_GET(DT_NODELABEL(soil_pwm));
static const uint32_t pulse = DT_PROP(DT_NODELABEL(soil_pwm), pulse);

// Calibration coefficients for the soil sensing circuit.
static const int dry_coeffs[3] = DT_PROP(DT_NODELABEL(soil_calibration_coeffs), dry);
static const int wet_coeffs[3] = DT_PROP(DT_NODELABEL(soil_calibration_coeffs), wet);

// Soil PWM drive voltage. REGOUT0 regulates VDD to a fixed rail, so the
// drive amplitude no longer tracks the battery and the dry/wet endpoints
// must be evaluated at that constant — otherwise reported moisture would
// drift as the CR2032 discharges. Boards without a REGOUT0 choice (i.e.
// not nRF52840) fall back to the legacy battery-voltage evaluation.
#if defined(CONFIG_BPARASITE_REGOUT0_1V8)
#define PRST_SOIL_VDRIVE_FIXED 1.8f
#elif defined(CONFIG_BPARASITE_REGOUT0_2V1)
#define PRST_SOIL_VDRIVE_FIXED 2.1f
#elif defined(CONFIG_BPARASITE_REGOUT0_2V4)
#define PRST_SOIL_VDRIVE_FIXED 2.4f
#elif defined(CONFIG_BPARASITE_REGOUT0_2V7)
#define PRST_SOIL_VDRIVE_FIXED 2.7f
#elif defined(CONFIG_BPARASITE_REGOUT0_3V0)
#define PRST_SOIL_VDRIVE_FIXED 3.0f
#elif defined(CONFIG_BPARASITE_REGOUT0_3V3)
#define PRST_SOIL_VDRIVE_FIXED 3.3f
#endif

struct gpio_dt_spec fast_disch_dt =
    GPIO_DT_SPEC_GET(DT_NODELABEL(fast_disch), gpios);

// Shared buffer and adc_sequennce.
static int16_t buf;
static struct adc_sequence sequence = {
    .buffer = &buf,
    .buffer_size = sizeof(buf),
};

static const struct adc_dt_spec adc_soil_spec =
    ADC_DT_SPEC_GET_BY_IDX(DT_PATH(zephyr_user), 0);

static const struct adc_dt_spec adc_batt_spec =
    ADC_DT_SPEC_GET_BY_IDX(DT_PATH(zephyr_user), 1);

#if DT_NODE_EXISTS(DT_NODELABEL(photo_transistor))

static const struct adc_dt_spec adc_photo_transistor_spec =
    ADC_DT_SPEC_GET(DT_NODELABEL(photo_transistor));
struct gpio_dt_spec photo_transistor_enable_dt =
    GPIO_DT_SPEC_GET(DT_NODELABEL(photo_transistor_enable), gpios);

#elif DT_NODE_EXISTS(DT_NODELABEL(ldr))

static const struct adc_dt_spec adc_ldr_spec =
    ADC_DT_SPEC_GET(DT_NODELABEL(ldr));
struct gpio_dt_spec ldr_enable_dt =
    GPIO_DT_SPEC_GET(DT_NODELABEL(ldr_enable), gpios);

#endif

typedef struct {
  // High (h) and low (p) voltage (v) and % (p) points.
  float vh, vl, ph, pl;
} batt_disch_linear_section_t;

static void set_battery_percent(const prst_adc_read_t* read, prst_batt_t* out) {
  // Must be sorted by .vh.
  static const batt_disch_linear_section_t sections[] = {
      {.vh = 3.00f, .vl = 2.90f, .ph = 1.00f, .pl = 0.42f},
      {.vh = 2.90f, .vl = 2.74f, .ph = 0.42f, .pl = 0.18f},
      {.vh = 2.74f, .vl = 2.44f, .ph = 0.18f, .pl = 0.06f},
      {.vh = 2.44f, .vl = 2.01f, .ph = 0.06f, .pl = 0.00f},
  };

  const float v = read->voltage;

  if (v > sections[0].vh) {
    out->percentage = 1.0f;
    return;
  }
  for (int i = 0; i < ARRAY_SIZE(sections); i++) {
    const batt_disch_linear_section_t* s = &sections[i];
    if (v > s->vl) {
      out->percentage = s->pl + (v - s->vl) * ((s->ph - s->pl) / (s->vh - s->vl));
      return;
    }
  }
  out->percentage = 0.0f;
  return;
}

static inline float eval_poly(const int coeffs[3], float x) {
  // The coefficients are specified times 1000, as a workaround the lack of support for floating
  // points in devicetree bindings.
  return (coeffs[0] + coeffs[1] * x + coeffs[2] * x * x) / 1000.0f;
}

static inline float get_soil_moisture_percent(float battery_voltage,
                                              int16_t raw_adc_output) {
#ifdef PRST_SOIL_VDRIVE_FIXED
  // Regulated VDD: dry/wet are constants from Kconfig (settable via
  // -DCONFIG_PRSTLIB_SOIL_DRY_RAW=…). The DT polynomial is bypassed.
  ARG_UNUSED(battery_voltage);
  const float x = PRST_SOIL_VDRIVE_FIXED;
  const float dry = (float)CONFIG_PRSTLIB_SOIL_DRY_RAW;
  const float wet = (float)CONFIG_PRSTLIB_SOIL_WET_RAW;
#else
  const float x = battery_voltage;
  const float dry = eval_poly(dry_coeffs, x);
  const float wet = eval_poly(wet_coeffs, x);
#endif
  const float percent = (raw_adc_output - dry) / (wet - dry);
  LOG_DBG("Read soil moisture 2: %.2f | Raw %u | V_drive: %.2f | Dry: %.2f | Wet: %.2f",
          DOUBLE_PROMO_OK(100 * percent),
          raw_adc_output, DOUBLE_PROMO_OK(x), DOUBLE_PROMO_OK(dry), DOUBLE_PROMO_OK(wet));
  return percent;
}

static int read_adc_spec(const struct adc_dt_spec* spec, prst_adc_read_t* out) {
  RET_IF_ERR(adc_sequence_init_dt(spec, &sequence));

  RET_IF_ERR(adc_read(spec->dev, &sequence));

  int32_t val_mv = buf;
  RET_IF_ERR(adc_raw_to_millivolts_dt(spec, &val_mv));
  val_mv = MAX(0, val_mv);

  out->raw = buf;
  out->millivolts = val_mv;
  out->voltage = val_mv / 1000.0f;
  return 0;
}

int prst_adc_init() {
  RET_IF_ERR(adc_channel_setup_dt(&adc_soil_spec));
  RET_IF_ERR(adc_channel_setup_dt(&adc_batt_spec));

  RET_IF_ERR(!device_is_ready(fast_disch_dt.port));
  RET_IF_ERR(gpio_pin_configure_dt(&fast_disch_dt, GPIO_OUTPUT));

#if DT_NODE_EXISTS(DT_NODELABEL(photo_transistor))
  RET_IF_ERR(adc_channel_setup_dt(&adc_photo_transistor_spec));
  RET_IF_ERR(!device_is_ready(photo_transistor_enable_dt.port));
  RET_IF_ERR(gpio_pin_configure_dt(&photo_transistor_enable_dt, GPIO_OUTPUT));
#elif DT_NODE_EXISTS(DT_NODELABEL(ldr))
  RET_IF_ERR(adc_channel_setup_dt(&adc_ldr_spec));
  RET_IF_ERR(!device_is_ready(ldr_enable_dt.port));
  RET_IF_ERR(gpio_pin_configure_dt(&ldr_enable_dt, GPIO_OUTPUT));
#endif

  for (size_t idx = 0; idx < ARRAY_SIZE(dry_coeffs); idx++) {
    LOG_DBG("Dry coeff %d: %d\n", idx, dry_coeffs[idx]);
  }
  for (size_t idx = 0; idx < ARRAY_SIZE(wet_coeffs); idx++) {
    LOG_DBG("Wet coeff %d: %d\n", idx, wet_coeffs[idx]);
  }
  return 0;
}

int prst_adc_batt_read(prst_batt_t* out) {
  RET_IF_ERR(read_adc_spec(&adc_batt_spec, &out->adc_read));
  // When the battery channel samples VDDH/5 instead of VDD, scale back up
  // so downstream code sees the true battery voltage.
  out->adc_read.millivolts *= CONFIG_PRSTLIB_BATT_VOLTAGE_DIVIDER;
  out->adc_read.voltage *= CONFIG_PRSTLIB_BATT_VOLTAGE_DIVIDER;
  set_battery_percent(&out->adc_read, out);
  return 0;
}
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

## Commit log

2026-05-17 Added required full name and optional vendor to board definition.
2026-05-17 Possible fixes for unused board qualifiers. Removed redefinition of included bool in hw model v2.
2026-05-17 Changed tooling to nrfutil since nrfprog is not available anymore. Removed obsolete comments in board cmake.
2026-05-19 Migrating action to zephyr setup action.
    Added folder for board definitions to west build.
    Added zigbee config flag for action.
    Explicitly setting path for non zigbee builds.
2026-05-22 Works with build-with-docker for zigbee
    [soil-calibration-coeffs.yaml]
2026-06-13 Ryan changes
    [parasite.kicad_pcb, parasite.kicad_sch]
2026-06-29 Fixed voltage
2026-07-13 Added constants from calibration
2026-07-14 1.8V sets UICR, More gh actions
2026-07-14 Fix CI and schematic pdf
    [parasite.kicad_sch]
